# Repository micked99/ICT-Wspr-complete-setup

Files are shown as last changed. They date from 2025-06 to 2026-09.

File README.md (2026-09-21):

## Consider a donation to this projects software developer at: https://yo3ict.uus.ro/index.html press the "Show Sponsors" button  <br>

### If you do find the following compilation of information of use - [Donation](https://www.paypal.com/donate/?business=FRB6FHBJRKUK8&no_recurring=0&currency_code=SEK) <br>

# ICT-v7-ATGM336
  <br> <br>
## Updates

Fixed a bug in telemetry/gps data and moved all configurable settings into the .ino file, like channel and tcxo freq

A 180° tx with a 4x power output avalible here: https://github.com/micked99/ICT-wspr-180-4x-the-power-output

BOM and Pick and place files added if you want to for example JLCPCB to make and assamble the complete board  

BOM_ict_v361-xs.csv & CPL_pick place_ict_v361-xs.xlsx  

Screenshots of the settings of order of pcb assembly, see folder "JLCPcb order"  

Get your board online onto Sondehub/aprs.fi section added  

## Introduction
This FW is mostly the work of Eduard YO3ICT,  you can read about here: https://yo3ict.uus.ro/tracker.html  
What I have done is to simplify it even more with a few less components and a slightly easier to solder pcb.

What Eduard did was reverse enginer the [QRP-Labs](https://shop.qrp-labs.com) telemetry protocol which use wspr to get data through, and open sourced it, details of the protocol is described here: https://qrp-labs.com/flights/s4#protocol 
most balloons use this encoding today, with a few exceptions, like [Zachtek](https://www.zachtek.com)  

Another good site for beginers is to read up and join the io board at: https://groups.io/g/picoballoon 

The [Traquito](https://traquito.github.io/)  page will host channel reservation and upload to varous tracking sites like https://aprs.fi/ and https://amateur.sondehub.org/ and as well host its own map, more maps and info avalible here https://lu7aa.org/dx.asp and here http://qrp-labs.com/tracking.html, another good page that poped up lately is [wsprtv](https://wsprtv.com/docs/user_guide.html#u4b-channel-map) & [wsprtv channel map](https://wsprtv.com/tools/channel_map.html?band=17m&num_days=30&rx_threshold=1)

## Folders in this repo:  
### ICT_WSPR   
The code to upload to the board  
### Libraries
Copy the content in this folder into libraries folder of Arduino C:\Program Files (x86)\Arduino\libraries  
### Pcb-ICT-main  
Cam files for pcb ordering as well as the Eagle schematic and board files, viewer for both files here: https://www.altium365.com/viewer/
### Boards.txt-main  
Replace the Boards.txt in arduino to controll the speed of the 328, its located in: C:\Program Files (x86)\Arduino\hardware\arduino\avr  
### oscillator-main  
Test file to test the 328 and si5351, no gps is needed for this, only the 328, 5351, its tcxo and the two pull up resistors have to be soldered, if all works it will tx a carrier at 14.097Mhz, upload the .ino file with arduino or the .hex with Avrdudess https://github.com/ZakKemble/AVRDUDESS

## Goals  
This setup is aimed at three main things: light weight, low power demands and as few components as possible - easy to build

The board can be built to weigh below 1 gram fully assembled (pic below) with solar cells & antenna connected total weight 4-5 gram




To make the board consume as little power as possible its setup to switch between tx and gps so only one of the two is ON at any time, so it will startup and get valid gps lock with tx side of the board switched off, the tx ic - si5351 consumes 17-27mA (depending on model) in stb curent even when not in use so only the gps is on and draws about 25mA using the ATGM336 (N31), when the board have got a valid lock the gps will turn off and the wspr tx starts, using the low power 76, see further down, it will consume about 20mA in low and at max power, 79, it will be about 30mA, on top of this the 328 running at 2Mhz and the Tcxo combined will take another 3mA 

The board will work on any band between 80m and 2m but most used band is 20m-10m

# Features  
CW init - At power on, when sun hits the solar panels it start to tx cw, then you know you are good for launch  
Randomization - Randomize the tx by ca 5 hz each tx, have been turned off by deafult, enable in Timing.h  
No tx over selected grids - Move tx to ism (13.555) freq over selected grids  
Powerswitching between gps and tx - Will put less stress on the cells and get earlier in the morning startups  
Course altitude in main wspr - Will insert a rough altitude into the standard wspr db field, see TelemFunctions.h  
Slowly increased power in 4 steps - Default setting is 79 - Max power  
Good WDT function of 328 - Will never fail to wake up even with unstable solar cells powering the board  
Will work at low clocks, tested down to 1Mhz on the 328 - Deafult is 2Mhz  
Powersave of gps by set it to single navigational system  - See Gps section  

# GPS:

The ATGM336-N31 support both GPS and Beidou system, by switching off Beidou and run the ATGM in GPS only mode we save about 4mA, see .ino file for the command, gps only is activated by default.  
This gps does not have any altitude limit like many other modules, its been tested to 150.000m with a hack-rf and GPSSim and still worked fine

# BOM

All components but the si5351 is bought on Aliexpress, you can source the SI535/MS5351 on Ali but they can have an higher power consumption then the original, from my experience the Ali ones draw 27mA instead of 17mA in stb current  
----------------  
Cpu ATmega328

Gps ATGM336 (N31) others will work  

TX Si5351  

Tcxo 25/26/27 Mhz size 3225 3.2x2.5mm  

Xo 4Mhz size 4520 4.5mm×2mm   

2x 10K resistor size 0603, value non critical, 1K-10K works  

2x 100nF Capacitor size 0603, value non critical 10-470nF works, it will work fine without any soldered on but I recommend at least one  

2.54mm x2 Pin Header - Remove before flight by cutting it of with a scissor  

# Antennas

For gps antenna use a 46mm wire which represents a 1/4 antenna at 1575Mhz  

For tx antenna I use 0,15mm which is a good combination of strength and weigh but any wire in the 0,1 - 0,2mm will work fine.  

I use a small hook 2cm long made of 0,6mm wire bottom, and 0,8mm at the top to solder on the antenna wire, solder and twist a couple of turns arround the hook  
  <br>  
Here is good picture where you can see the Red and Yellow gps antennas  
  <br>  

Tx Antenna length calculated as normal, 300/freq x 0.95 /4

Upper antenna leg should be supported by some sort of fishing line taped to the balloon

# Solar cells

6 psc of solar cells connected in series will work fine, or 4 psc of a bit larger cells and a voltage doubler with 3,3V ldo like REG710 will do the work, ready made pcb are avalible on Aliexpress, search for "Low Noise Regulated Charge Pump" see below pic  
  <br> 

Do not try use converters with an inductor, they will not work, only converters using a capacitor are likeley to succeed.  

As can be seeen in the below picture the solar cells is intended to be soldered to the board with a center copper rod of 0,8mm, notice,  
there are two pairs of vias, one is GND and one pair is not connected to anything which is where you solder the center support for the cells - see below pic  
  <br>  
OBS! The programming pinhead should be cutoff before flight and preferably before you solder the cells onto the pcb  

solderpoints <br> 
Solderpoints for the solar cells  

With 6 x 38x19 cells ounded flat you can see a startup of the board at about 13° solar angle 

How I solder the cells together, I use a 0,6mm wire I extract from a multi stranded electrical cable, and then a very thin wire from an even smaller multi stranded cable to solder the cells to the pcb, pics:

  <br>  
  <br>  

To test the solar + board indoor before a flight you can use a Halogen flood light like below pic, I use a 400W, 8545 lumen lamp.  
-OBS- Led lamps wont work.

  <br>  

# Arduino

To compile and upload the sketch I use Arduino version 1.8.13 which you find here, others will work but not tested, https://www.arduino.cc/en/software/OldSoftwareReleases/

# 328 Fuses

Sets the expected external or internal xo used and also set the brownout to 1,8V

The 328 have an internal xo at 8Mhz, you can set it to be divided down by 8 (fuse) and then the board runs at 1Mhz
the internal xo at 8Mhz is not very stable in cold and it will not work at flying altitude, but I have tried a few flights on the internal xo divided down to 1Mhz 
and it have worked fine, anyway, both speeeds works fine for testing a board on the bench, but I do recomend that you use the suggested 4Mhz xo as in the schematic.

FD D9 FE 1,8V / External 2/4/8Mhz xo  - This is the fuses you should use if you build this board  

62 D9 FE 1.8V / internal 8Mhz osc /div8 = 1Mhz  
E2 D9 FE 1.8V / internal 8Mhz osc  

To set fuses use Avrdudess https://github.com/ZakKemble/AVRDUDESS

Fusecalc page https://www.engbedded.com/fusecalc/

I would recommend to buy a couple of arduino nano boards to practice on before flashing fuses onto a built board, as this is the main culprit of non responsive 328 - wrongly set or corrupted fuses

# Programming

The pcb is fited with a 6 pin ISP connector  
The Arduino uploads the fw with an USBasp programmer, get a 3,3v version with a 10 to 6 pin header adapter on the end of the ribbon cable  
To upload a .hex file like the one supplied in oscillator-main folder I recommend using AVRDUDESS - A GUI for AVRDUDE

https://blog.zakkemble.net/avrdudess-a-gui-for-avrdude/  
https://github.com/avrdudes/avrdude/  

Use libsusbK in Zadig to install driver for the Usbasp: https://zadig.akeo.ie/

  <br>  

In Arduino IDE select Usbasp as programmer:    
  <br>

In Boards select rAVA 2Mhz:    
  <br>  
# PCB  

  <br>  

I have always used Jlcpcb at https://jlcpcb.com/ for my balloon boards and other projects

The pcb files have been made with Eagle pcb nowadays under the name Autodesk Eagle https://www.autodesk.com/products/eagle/overview

Make the PCB as thin as possible to save weight, 0,6mm is good compromise between weight and price

In Pcb-ICT-main folder in this repo you will find needed CAM files in the zip´s, if you are a experieced with solder small parts and have a hot air solder station go with the Xtra Smal QFN version (ict_v361-xs.zip) of the board, for a more simple soldering setup use the TQFP version (ict_v361.zip)

TQFP 


Here is what a JLC-PCB assambled board looks like, pictures from Michael KC3GMG  
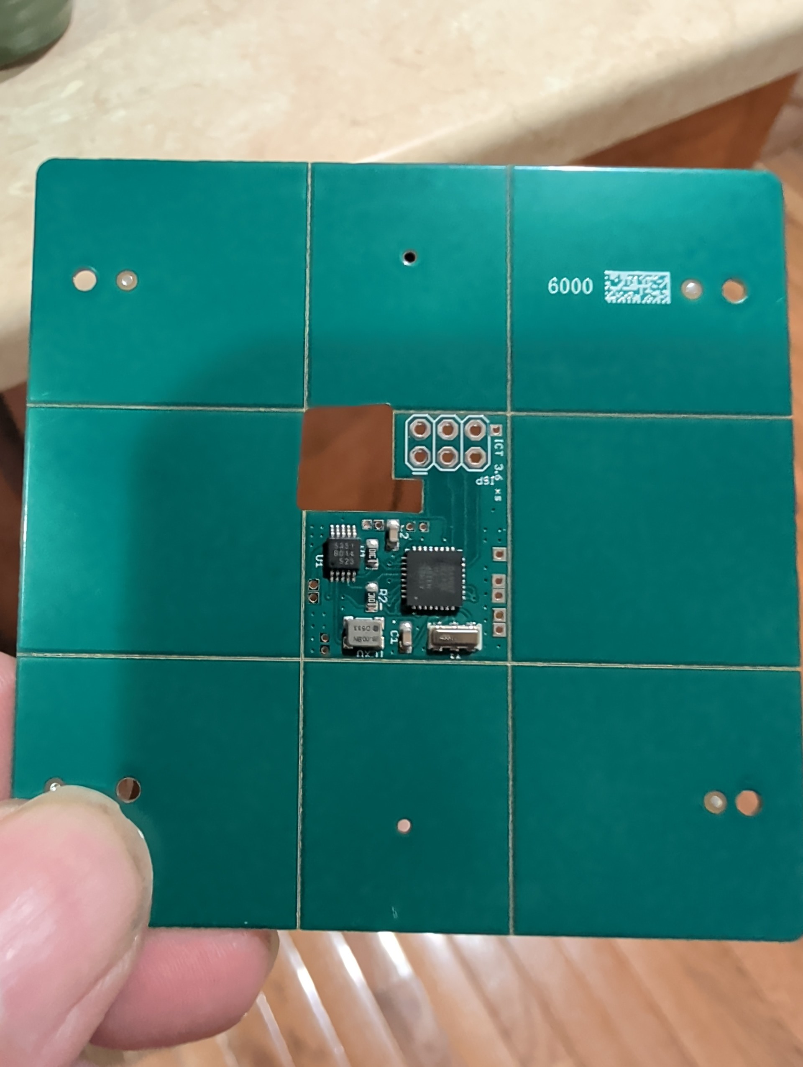
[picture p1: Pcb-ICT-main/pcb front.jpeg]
  
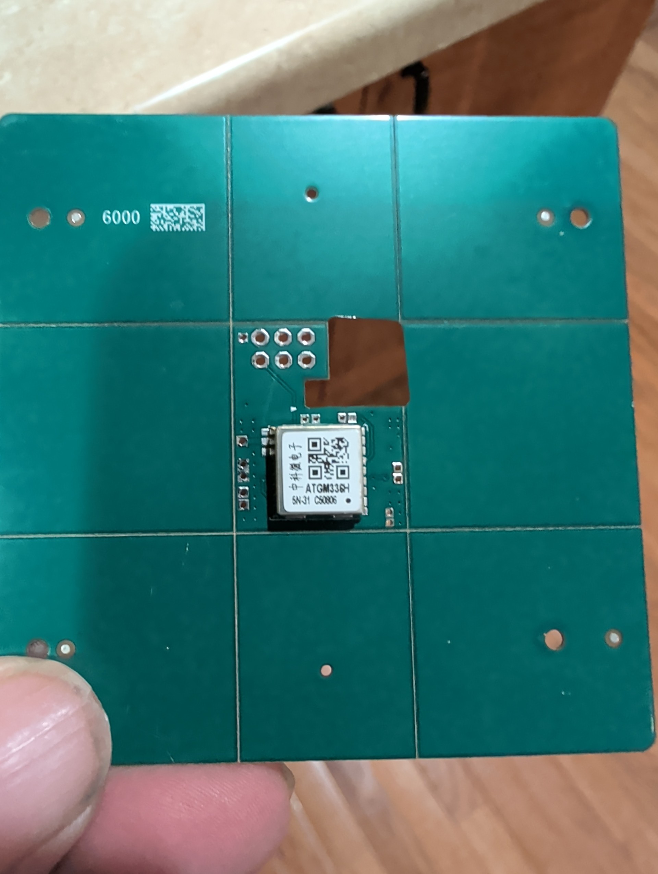
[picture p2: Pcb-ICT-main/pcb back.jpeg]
  

# Schematic  



# Setup parameters in the code  
The Arduino code is setup from start to use a 26Mhz Tcxo and to use a 4Mhz xo divided by 2 to run at 2Mhz, if other values used the code needs to be changed - see below  

Values to edit in the ino file  <br>
Follow the <<<<< arrows where you need to edit <br>

Sets the frequency and band  <br>
#define WSPR_FREQ     14097190UL // <<<<< SET TX FREQUENCY HERE <<<<<<<<<<<<<<<<<<<<<<<<<<<<<<br>

Sets your call and channel<br>
const char call[] = "SA7BSS";   // <<<<< SET WSPR CALLSIGN <<<<<<<<<<<<<<<<<<br>
char tlm_channel1 = 'Q';        // <<<<< SET TELEMETRY CHANNEL 0/1/Q <<<<<<<<br>
char tlm_channel2 = '9';        // <<<<< SET TELEMETRY CHANNEL 0-9 <<<<<<<<<<br>
 
See this page for channel setup and reservation: https://traquito.github.io/channelmap/

Set initial power of the 5351  
int pwr_level=79;  
it will for every sequence increase the power one step so if you set it at 77 it will take two sequencies, 20 min before it will start at full power   
avalible valus are 76, 77, 78 and 79 where 79 is max power, 76 is just a few mW so I recommend not to use that, the default setting is max power 79

CW setup, the board will at first moment at power on send a morse signal with your callsign<br>
Here is my SA6BSS call in the ino file  <br>
cw_s(); cw_a(); cw_6(); cw_b(); cw_s(); cw_s();  <br>

Sets the frequncy of tcxo used for the si5351 <br>
tcxo  = 26000000UL;   // <<<<< SET TCXO FREQUENCY HERE <<<<<<<<br>

Testing and Scheduling of tx sequence<br>

#include "Timing-test.h"  // <<<<< Set Timing-test.h for testing, it will tx on first 2 min slot after power on <<<<<<<<<<  <br>
#include "Timing.h"       // <<<<< Set Timing.h for flight and it will tx on the nominal 10 min scheduling <<<<<<<<<<<<<<<  <br>

Timing-test.h is a testfile that will start tx every 2min, this it convinient to use during testing on the bench, final prep before flight is to edit the  
.ino file from #include "Timing-test.h" to #include "Timing.h" this is the main config that should be used during a flight, it have a 10 min sequence as needed to fit the scheduling agreed on in the balloon community
Edit Timing.h sceduling at what minute you want to tx your normal wspr and at what minute to tx the telemetry, this can be done inside Arduino ide or with a normal texteditor  

To adjust the sequence in what order the standard and telemtry is transmitted edit Timing.h, it is set to transmitt 4 times - 8 minutes and then switching off the radio and enable gps, gets new loction data last 2 min of the 10 minute slot, then start over, default setting is: WSPR, WSPR_telemtry, WSPR, WSPR, this is set by adjusting the setModeWSPR();  or  setModeWSPR_telem(); in Timing.h file  

This is the standard setup using a 4 Mhz xo, so if you build the board with the recommended components and downloaded fw this does not need to change
Sets speed of the board  
clock_prescale_set(clock_div_2);  or clock_prescale_set(clock_div_4);  
this in conjuction with:    
#define WSPR_CTC 1334  
and select rAVA 2Mhz from boards in Arduino boards 

Alternative clocksettings:  
WSPR CTC - 2668 @ 4Mhz //1334 @ 2Mhz //667 @ 1Mhz  
And to select the appropriate board setting under Boards in Arduino,  
lets say we want to set the board to 1Mhz using a 4Mhz xo we need to set the prescaler to  
clock_prescale_set(clock_div_4);   
and set  
WSPR CTC 667  
and then select gAVA 1Mhz under boards, see section Programming  

then, for example if you wan to run it a 4Mhz set:
WSPR CTC - 2668  
mark out both of the //clock_prescale_set  
and use hAVA 4Mhz board setting  

to set cw tx frequncy adjust it in Beep.h, this will tx a short cw init as soon as you connect power<br>
     freq = 14096980UL;  <br>
  // freq = 18105900UL;  <br>
  // freq = 28125870UL;  <br>

If you have problem getting wspr decodes, say its works fine on 20m but when you try 10m the board tx but you dont get any decodes,
change this in TelemFunctions.h <br>

 //outdivider 77000000000 or 30000000000 // If bad decodes at 24/28Mhz try the other value<br> 
  outdivider = 30000000000 / frequency;  // With 900 MHz beeing the maximum internal PLL-Frequency<br> 

# Balance the board

You want the board to be as leveled as possible so the solarcells always points up and not to the sides,  
to do this use the top hook, puti it on a short loop of fishing line and bend the copper rod untill it levels up, see below:  

  <br> 

# Get your flight uploaded to Sondehub and/or aprs.fi

There is a couple of ways to get your board onto [Sondehub](https://amateur.sondehub.org/) 

The way Im doing it is to use a wspr-to-sondehub python script described here: https://github.com/micked99/wspr-to-sondehub-script
What I do is to use this script with a filtering function so your upload data dont get mixed with other flights - you should check the channel is free here before relesing a balloon:  [WSPR-TV](https://wsprtv.com/tools/channel_map.html?band=17m&num_days=30&rx_threshold=1) but as the 600 channels per band is relaying on filtering on frequency and this script cant handle that, this is a simple workarround.
So the idea I got and that DG4NOB implemented in the python upload code was that we can use the voltage reading of the battery as a filtering function, as we use solar cells, voltage is mostly of no interest, reading the Encoding [Description](https://qrp-labs.com/flights/s4#protocol) we see "Battery voltage is coded by a number in the range 0..39, which represents battery voltage in the range 3.00 to 4.95V with a resolution of 0.05V" this means we have 40 unique "channels" within this, so what we can do is to set a static value in the ict fw and uplod this to the board, <br> 
look at lines 126 - 132 in TelemFunctions.h and you see this:<br> 

  sensorVolt = sensorVolt / 5;   // mark out for fixed voltage<br> 
  volt = sensorVolt * 1.1f;      // mark out for fixed voltage<br> 
  volt = volt / 1023.0f;         // mark out for fixed voltage<br> 
  volt = volt * 4.18f;           // mark out for fixed voltage<br> 
  // volt = 3.94;                // --Remove if sensor voltage is used--<br>
  if (volt < 3.0) volt = 3.0;    // mark out for fixed voltage<br>
  if (volt > 4.95) volt = 4.95;  // mark out for fixed voltage<br>   

The normal setup is as above where the adc reads the voltage on sensorpin, it should be a voltage divider there but I have routed the pin directly to vcc so if you dont make any edits to the code it will constantly read 4.56V, so what we can do is to change the code, say we want to filter the voltage to 3,94V we edit the code to:  

 // sensorVolt = sensorVolt / 5;   // mark out for fixed voltage<br>
 // volt = sensorVolt * 1.1f;      // mark out for fixed voltage<br>
 // volt = volt / 1023.0f;         // mark out for fixed voltage<br>
 // volt = volt * 4.18f;           // mark out for fixed voltage<br>
    volt = 3.94;                   // --Remove if sensor voltage is used--<br>
 // if (volt < 3.0) volt = 3.0;    // mark out for fixed voltage<br>
 // if (volt > 4.95) volt = 4.95;  // mark out for fixed voltage<br>

After we done this and upload the code to the pcb we should have a fixed voltage reading constantly sending 3,94V which we can put in the balloon.ini file in the  [wspr upload script](https://github.com/micked99/wspr-to-sondehub-script)  

If you have launched the board with no editing to the ict code you can set 4,56V as a filter, this making it work on boards allready in flight.  

You need to double check the voltage readign your board actually tx as there will be a 0,01V variation on the actual value that comes out of the decoder, even if you set 3,94V it might be 3,95 that comes out, you can test it in this xls  
https://qrp-labs.com/images/ultimate3builder/ve3kcl/s4/308d.xls  
originating from https://qrp-labs.com/flights/s4#protocol  

Other ways to get you board online is to use https://lu7aa.org.ar/wsprset.asp  

There is also an uploader by Bill WB8ELK - maker of [Skytracker](https://elktronics.com) that you can download from [Here](https://groups.io/g/picoballoon/message/23150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)  
You need to be a member of this io board to access it, it will upload to aprs.fi and Sondehub will then automaticly pipe it onto its site,  
pros of this program is easy to setup and it can filter on Frequency as the 600 channel mapping require.  

# Misc pictures

  <br> 
  <br>

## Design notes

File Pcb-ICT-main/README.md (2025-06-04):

# ICT-PCB

Eagle PCB for my modified version of the ICT wspr setup 

This pcb is made and setup for my current version of the the ict code

ict_v361-xs // Extra small, using the QFN/MLF version of the 328 - Verified working

ict_v361 // Normal size, using the TQFP version of the 328 - untested but should work

Use .zip files for pcb ordering

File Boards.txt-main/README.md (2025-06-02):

# Boards.txt
Drop this file in Arduino IDE, it will ad the possibility to run the board at any speed of the following: 1, 2, 4, 8 & 16Mhz 

Set the prescaler, in this setup the used XO is dived with 4, so if you run a 8Mhz xo the board will run at 2Mhz            
  //clock_prescale_set(clock_div_2);             
  clock_prescale_set(clock_div_4);               
  //clock_prescale_set(clock_div_8);                    
  
edit this line: #define WSPR_CTC  1334   // CTC value for WSPR - 10672 @ 16Mhz //5336 @ 8Mhz //2668 @ 4Mhz //1334 @ 2Mhz //667 @ 1Mhz
and last choose the correct Speed under: Tools - Boards in IDE which should in this example be 2Mhz

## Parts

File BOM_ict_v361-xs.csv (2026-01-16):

Designator | Footprint | Quantity | Value | LCSC Part #
C1, C2 | 603 | 2 | C100nF_0603 | C14663
R1, R2 | 603 | 2 | R10k_0603 | C98220
GPS | SMD,9.7x10.1mm | 1 | ATGM336h-N31 | C90770
U1 | MSOP-10 | 1 | SI5351A-B-GTR | C504891
U2 | VQFN-32(5x5) | 1 | ATMEGA328P-MU | C7499261
TCXO | SMD3225-4P | 1 | KDS 1XTW26000MAA | C213404
Y1 | SMD4520-3P | 1 | CSTCR4M00G53-R0 | C22122

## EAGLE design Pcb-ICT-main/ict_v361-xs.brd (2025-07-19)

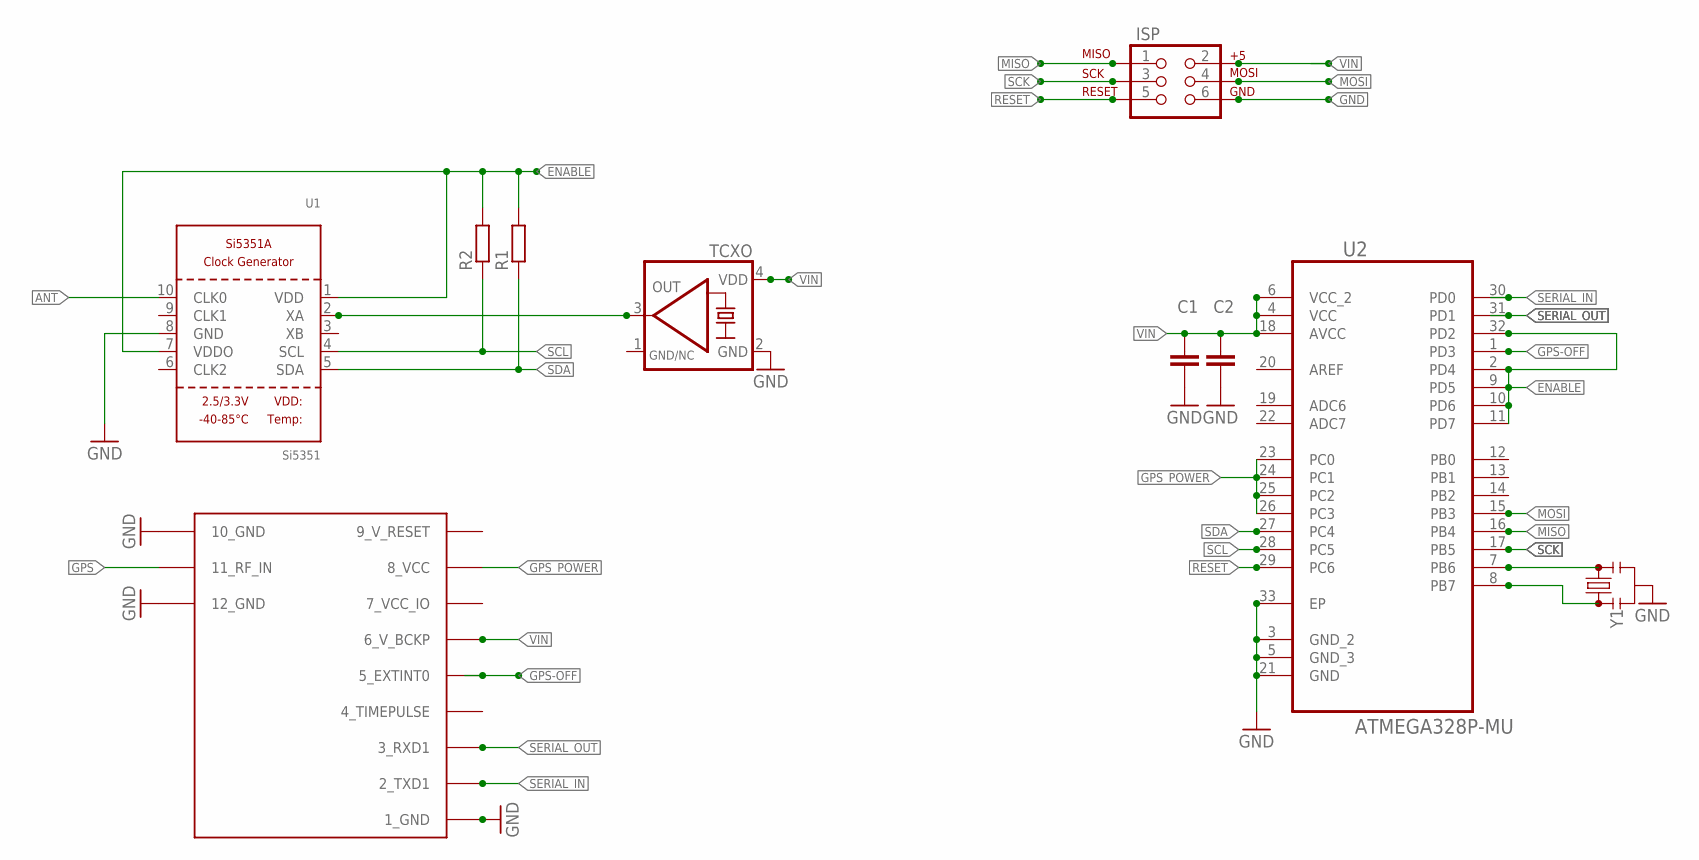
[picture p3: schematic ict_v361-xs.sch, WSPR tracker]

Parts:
C1, C2: C-EUC0603K; C0603K
GPS: UBLOX_MAX
ISP: AVR_SPI_PRG_6PTH; 2X3
R1, R2: R-EU_R0603; R0603
TCXO: KXO-TCXO-CMOS-84; 3.2X2.5_KXO-84-TCXO
U1: Si5351; MSOP10
U2: ATMEGA328P-MU; QFN50P500X500X100-33N
Y1: RESONATORSMD-4.5X2.0; RESONATOR-SMD-4.5X2.0

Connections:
7_VCC_IO: GPS.7_VCC_IO
9_V_RESET: GPS.9_V_RESET
ANT: U1.10 (CLK0)
ENABLE: R1.2, R2.2, U1.1 (VDD), U1.7 (VDDO), U2.2 (PD4), U2.9 (PD5), U2.10 (PD6), U2.11 (PD7), U2.32 (PD2)
GND: C1.2, C2.2, GPS.1_GND, GPS.10_GND, GPS.12_GND, ISP.6, TCXO.2 (GND), U1.8 (GND), U2.3 (GND_2), U2.5 (GND_3), U2.21 (GND), U2.33 (EP), Y1.2
GND/NC: TCXO.1 (GND/NC)
GPS: GPS.11_RF_IN
GPS-OFF: GPS.5_EXTINT0, U2.1 (PD3)
GPS_POWER: GPS.8_VCC, U2.23 (PC0), U2.24 (PC1), U2.25 (PC2), U2.26 (PC3)
MISO: ISP.1, U2.16 (PB4)
MOSI: ISP.4, U2.15 (PB3)
unnamed: U2.7 (PB6), Y1.3
unnamed: U2.8 (PB7), Y1.1
unnamed: TCXO.3 (OUT), U1.2 (XA)
RESET: ISP.5, U2.29 (PC6)
SCK: ISP.3, U2.17 (PB5)
SCL: R2.1, U1.4 (SCL), U2.28 (PC5)
SDA: R1.1, U1.5 (SDA), U2.27 (PC4)
SERIAL_IN: GPS.2_TXD1, U2.30 (PD0)
SERIAL_OUT: GPS.3_RXD1, U2.31 (PD1)
VIN: C1.1, C2.1, GPS.6_V_BCKP, ISP.2, TCXO.4 (VDD), U2.4 (VCC), U2.6 (VCC_2), U2.18 (AVCC)

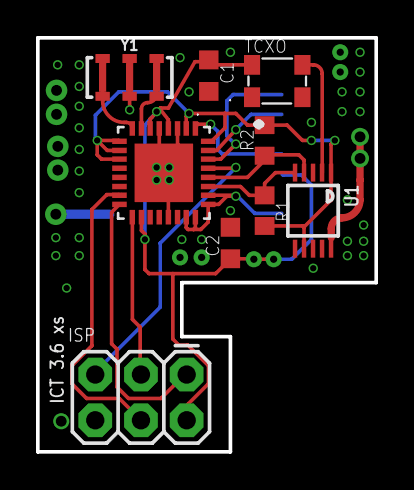
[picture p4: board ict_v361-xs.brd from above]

Board: 2 copper layers, 18.8 x 23.0 mm, 10 parts (1 on the bottom side), 16 nets.

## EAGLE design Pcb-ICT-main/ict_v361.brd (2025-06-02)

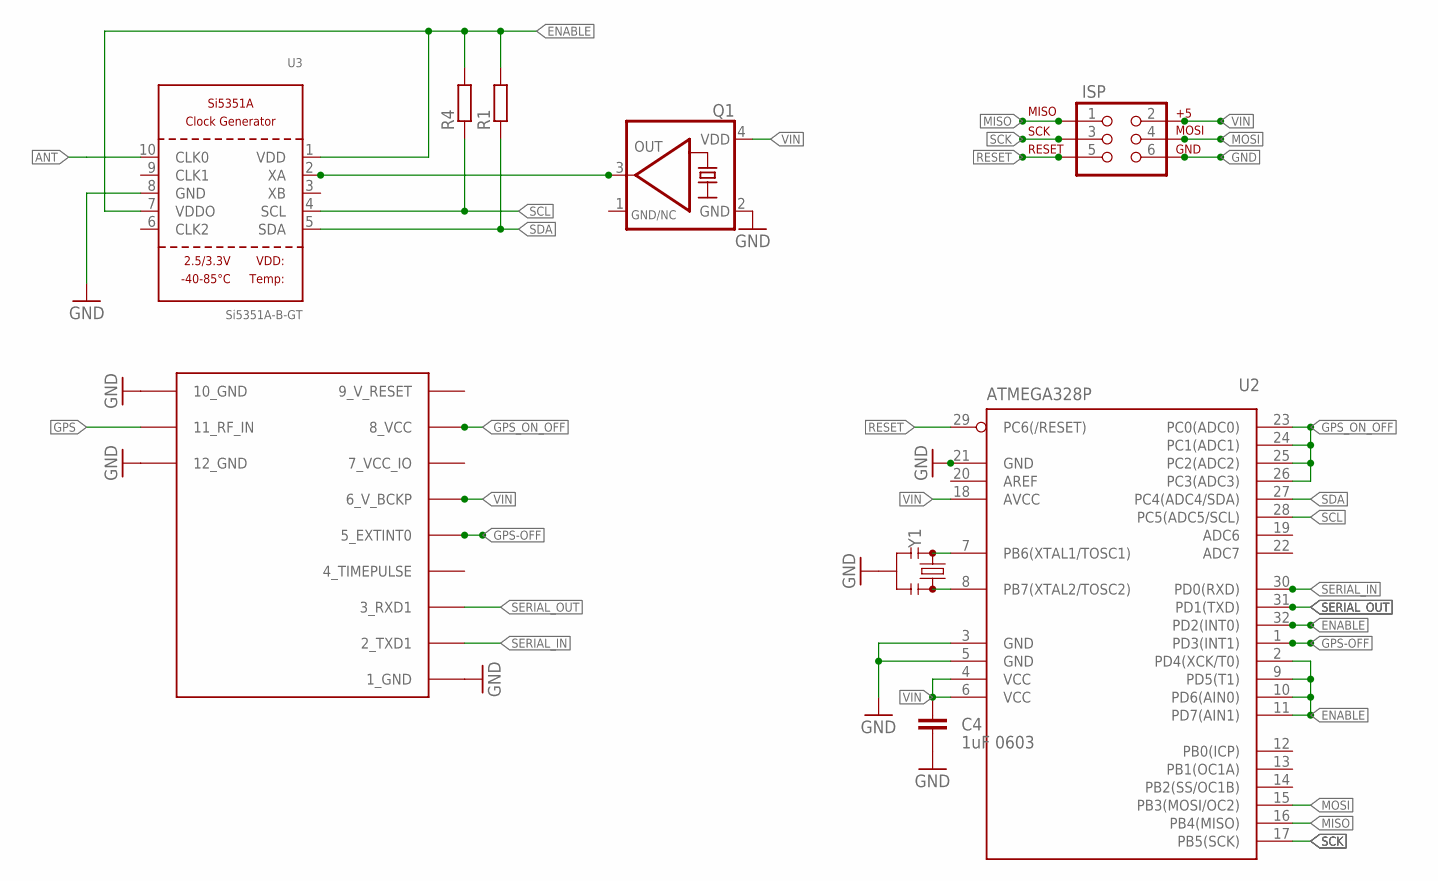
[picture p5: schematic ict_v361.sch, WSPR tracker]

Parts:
C4: 1uF 0603; C0603K
ISP: AVR_SPI_PRG_6PTH; 2X3
Q1: KXO-TCXO-CMOS-84; 3.2X2.5_KXO-84-TCXO
R1, R4: R-EU_R0603; R0603
U2: ATMEGA328P; TQFP32-08
U3: Si5351A-B-GT; MSOP10
U$2: UBLOX_MAX
Y1: RESONATORSMD-4.5X2.0; RESONATOR-SMD-4.5X2.0

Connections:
7_VCC_IO: U$2.7_VCC_IO
9_V_RESET: U$2.9_V_RESET
ANT: U3.10 (CLK0)
ENABLE: R1.2, R4.2, U2.2 (PD4(XCK/T0)), U2.9 (PD5(T1)), U2.10 (PD6(AIN0)), U2.11 (PD7(AIN1)), U2.32 (PD2(INT0)), U3.1 (VDD), U3.7 (VDDO)
GND: C4.2, ISP.6, Q1.2 (GND), U2.3 (GND), U2.5 (GND), U2.21 (GND), U3.8 (GND), U$2.1_GND, U$2.10_GND, U$2.12_GND, Y1.2
GND/NC: Q1.1 (GND/NC)
GPS: U$2.11_RF_IN
GPS-OFF: U2.1 (PD3(INT1)), U$2.5_EXTINT0
GPS_ON_OFF: U2.23 (PC0(ADC0)), U2.24 (PC1(ADC1)), U2.25 (PC2(ADC2)), U2.26 (PC3(ADC3)), U$2.8_VCC
MISO: ISP.1, U2.16 (PB4(MISO))
MOSI: ISP.4, U2.15 (PB3(MOSI/OC2))
unnamed: U2.8 (PB7(XTAL2/TOSC2)), Y1.3
unnamed: U2.7 (PB6(XTAL1/TOSC1)), Y1.1
unnamed: Q1.3 (OUT), U3.2 (XA)
RESET: ISP.5, U2.29 (PC6(/RESET))
SCK: ISP.3, U2.17 (PB5(SCK))
SCL: R4.1, U2.28 (PC5(ADC5/SCL)), U3.4 (SCL)
SDA: R1.1, U2.27 (PC4(ADC4/SDA)), U3.5 (SDA)
SERIAL_IN: U2.30 (PD0(RXD)), U$2.2_TXD1
SERIAL_OUT: U2.31 (PD1(TXD)), U$2.3_RXD1
VIN: C4.1, ISP.2, Q1.4 (VDD), U2.4 (VCC), U2.6 (VCC), U2.18 (AVCC), U$2.6_V_BCKP

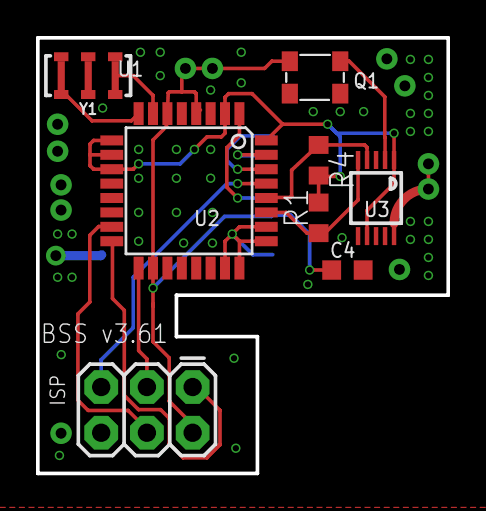
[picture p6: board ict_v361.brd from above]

Board: 2 copper layers, 22.8 x 24.2 mm, 9 parts (1 on the bottom side), 16 nets.

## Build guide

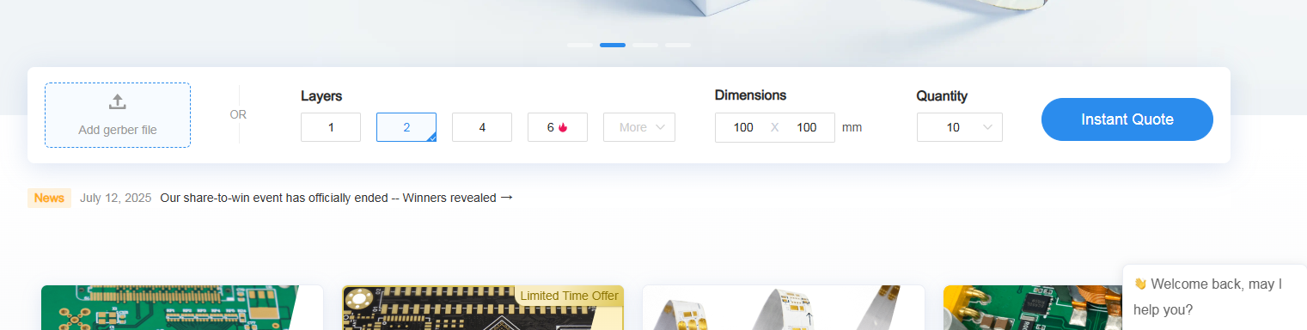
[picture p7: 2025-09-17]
JLCPcb order/2025-07-20 09_04_47-PCB Prototype & PCB Fabrication Manufacturer - JLCPCB.png

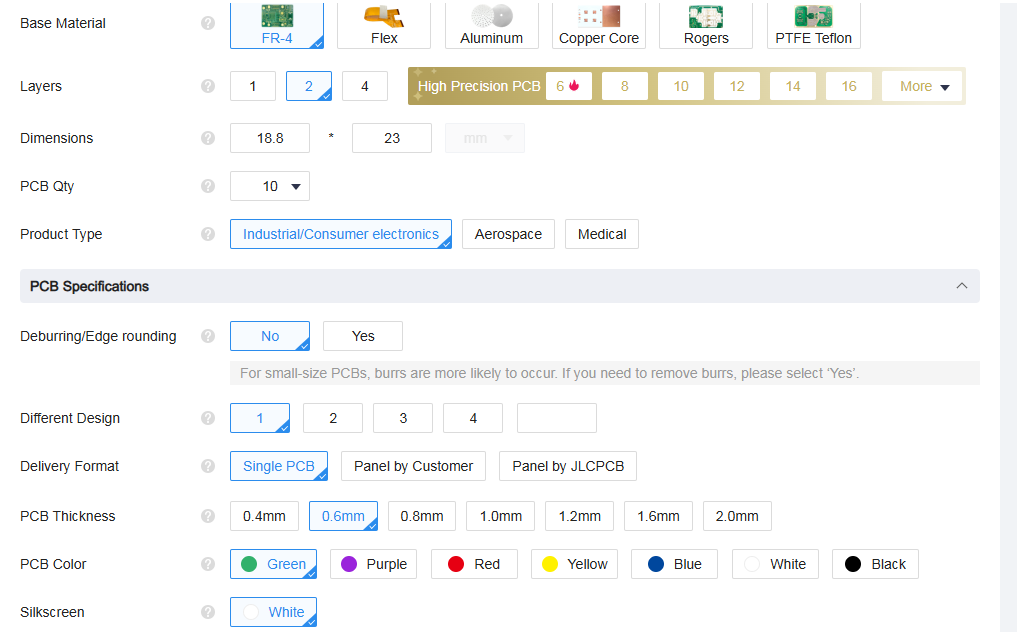
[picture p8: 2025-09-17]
JLCPcb order/2025-07-20 09_05_32-PCB Prototype & PCB Fabrication Manufacturer - JLCPCB.png

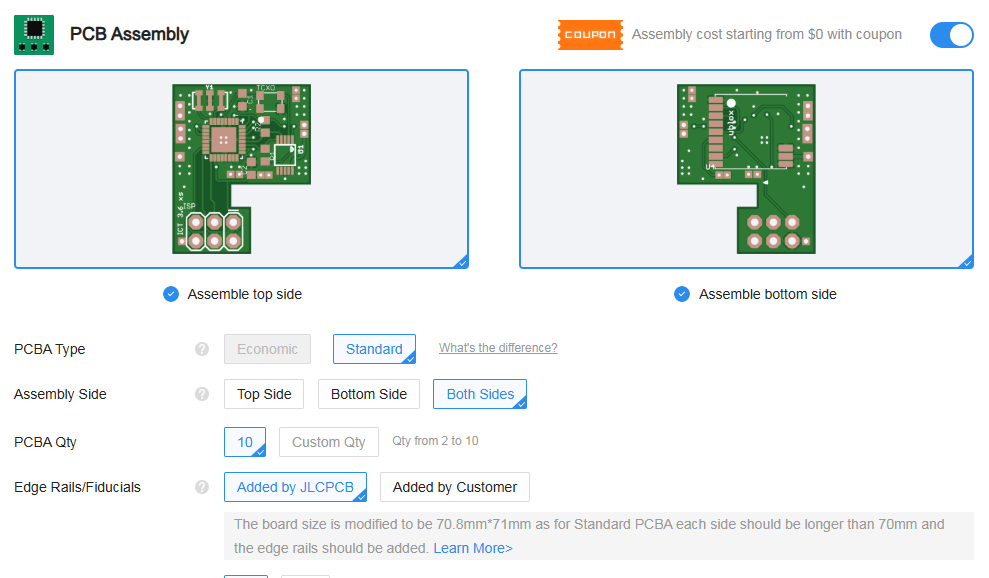
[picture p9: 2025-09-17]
JLCPcb order/2025-07-20 09_06_27-PCB Prototype & PCB Fabrication Manufacturer - JLCPCB.png

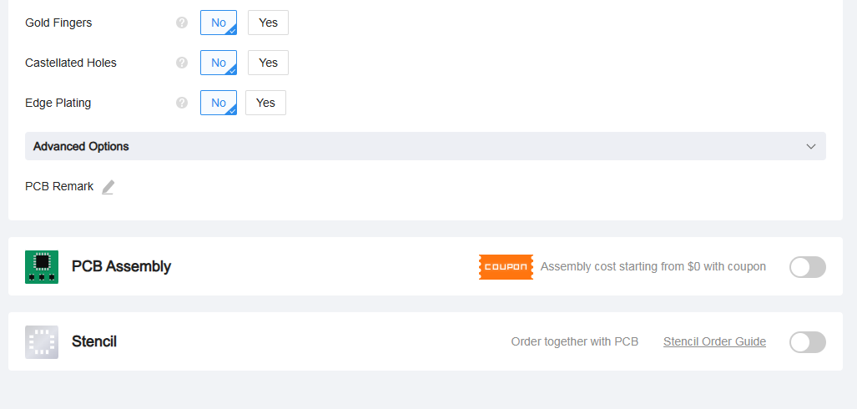
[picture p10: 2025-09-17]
JLCPcb order/2025-07-20 09_05_48-PCB Prototype & PCB Fabrication Manufacturer - JLCPCB.png

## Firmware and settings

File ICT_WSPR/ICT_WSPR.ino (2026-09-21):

//#pragma GCC diagnostic error "-Wconversion"

/*
   HABalloon by KD2NDR
   Improvements by YO3ICT
   Improvements By SA6BSS
   You may use and modify the following code to suit your needs so long as it remains open source and it is for non-commercial use only.
*/

#include <avr/wdt.h>
#include <TimeLib.h>
#include <TinyGPS++.h>
#include <JTEncode.h>
#include <Wire.h>
#include <avr/pgmspace.h>
#include <avr/power.h>

//#define WSPR_FREQ     3570185UL  // <<<<< SET TX FREQUENCY HERE <<<<<<<<<<<<<<<<<<<<<<<<<<<<<
//#define WSPR_FREQ     7040185UL  // <<<<< SET TX FREQUENCY HERE <<<<<<<<<<<<<<<<<<<<<<<<<<<<<
//#define WSPR_FREQ     10140285UL // <<<<< SET TX FREQUENCY HERE <<<<<<<<<<<<<<<<<<<<<<<<<<<<<
#define WSPR_FREQ     14097190UL   // <<<<< SET TX FREQUENCY HERE <<<<<<<<<<<<<<<<<<<<<<<<<<<<<
// #define WSPR_FREQ    18106230UL // <<<<< SET TX FREQUENCY HERE <<<<<<<<<<<<<<<<<<<<<<<<<<<<<
//#define WSPR_FREQ     21096150UL // <<<<< SET TX FREQUENCY HERE <<<<<<<<<<<<<<<<<<<<<<<<<<<<<        
//#define WSPR_FREQ     28126235UL // <<<<< SET TX FREQUENCY HERE <<<<<<<<<<<<<<<<<<<<<<<<<<<<<
#define ISM_WSPR_FREQ   13555425UL // = 1,500Hz audio on 13.553.900 Mhz // 13555425UL New correct ism freq
#define WSPR_CTC        1334       // WSPR CTC - 2668 @ 4Mhz //1334 @ 2Mhz //667 @ 1Mhz


// Enumerations
enum mode {MODE_WSPR};
TinyGPSPlus gps;
JTEncode jtencode;

// Global variables
unsigned long freq;
const char call[] = "SA7BSS";   // <<<<< SET WSPR CALLSIGN <<<<<<<<<<<<<<<<<<<<<<<<<<<<<<<<<<<<<<<
char tlm_channel1 = 'Q';        // <<<<< SET TELEMETRY CHANNEL 0/1/Q <<<<<<<<<<<<<<<<<<<<<<<<<<<<<
char tlm_channel2 = '9';        // <<<<< SET TELEMETRY CHANNEL 0-9 <<<<<<<<<<<<<<<<<<<<<<<<<<<<<<<
uint32_t tcxo;                  // TCXO/crystal frequency in Hz, set in setup()
uint32_t pll_c;                 // "c" part of feedback multiplier XTAL->PLL, set in setup()
char call_telemetry[7];         // WSPR telemetry callsign
char loc_telemetry[5];          // WSPR telemetry locator
char TestGrid[5];               // Testing grid for Geofence
uint8_t dbm, dbm_telemetry;     // Standard WSPR dbm - coarse altitude & WSPR telemetry dbm
//char message_jt9[14] = "";    // JT9 Message (13 char limit)
char loc4[5];                   // 4 digit gridsquare locator
byte Hour, Minute, Second;      // Used for timing
long lat, lon, oldlat, oldlon;  // Used for location
uint8_t tx_buffer[255];         // WSPR Tx buffer
uint8_t symbol_count;           // JTencode
uint16_t tone_delay, tone_spacing, CTC; // JTencode
int alt_meters = 0;
int telemetry_set = 0;
int Sats = 0;
int gps_speed = 0;
volatile bool proceed = false;
long lastMillis = 0; 
int pwr_level=79;               // Set between 76-79, to slowly increase power to ease load on the solar cells at low solar angles, 76 is really low so use from 77 and up.
int w=1;
bool Outside = true;            // Geofence flag
//GeoFence grids by Matt Downs - 2E1GYP //Airborne transmissions of this sort are not legal over North Korea and Yemen
const char NoTXGrids[] PROGMEM = {"PN31 PN41 PN20 PN30 PN40 PM29 PM39 PM28 PM38 LK16 LK15 LK14 LK13 LK23 LK24 LK25 LK26 LK36 LK35 LK34 LK33 LK44 LK45 LK46 LK47 LK48 LK58 LK57 LK56 LK55"};

#include "TelemFunctions.h"     // Various telemetry functions
#include "Beep.h"               // Beeps and CW at power on
//#include "Timing-test.h"      // <<<<< Set Timing-test.h for testing, it will tx on first 2 min slot after power on <<<<<<<<<<
#include "Timing.h"             // <<<<< Set Timing.h for flight and it will tx on the nominal 10 min scheduling <<<<<<<<<<<<<<<

// Function Prototype
void wdt_init(void) __attribute__ ((naked, used, section(".init3")));
// Function Implementation
void wdt_init(void)
 {
  MCUSR = 0x00;  //Clear all reset flags
  WDTCSR |= (1 << WDCE) | (1 << WDE);
  WDTCSR = (1 << WDP3) | (1 << WDP0);
  return;
 }

void setup()
 {
  cli(); //Disable global interrupts
  WDTCSR |= (1 << WDCE) | (1 << WDE);
  WDTCSR = (0 << WDIE) | (1 << WDE) | (1 << WDP3) | (1 << WDP0);  // First enable the watchdog timer
  sei(); //Enable global interrupts

  tcxo  = 26000000UL;   // <<<<< SET TCXO FREQUENCY HERE <<<<<<<<<<<<<<<<<<<<<<<<<<<<<
  pll_c = 924000UL;     // "c" part of PLL feedback multiplier

  clock_prescale_set(clock_div_2);
  //clock_prescale_set(clock_div_4);

  pinMode(2, OUTPUT);  // Si5351 off
  pinMode(4, OUTPUT);
  pinMode(5, OUTPUT);
  pinMode(6, OUTPUT);
  pinMode(7, OUTPUT);
  
  cw_s(); cw_a(); cw_6(); cw_b(); cw_s(); cw_s(); // Set callsign of the CW id at startup
  
  delay(80);
  pinMode(A0, OUTPUT); // GPS VCC on
  pinMode(A1, OUTPUT);
  pinMode(A2, OUTPUT);
  pinMode(A3, OUTPUT);
  digitalWrite(A0, HIGH);
  digitalWrite(A1, HIGH);
  digitalWrite(A2, HIGH);
  digitalWrite(A3, HIGH);
  delay(1500);
  Serial.begin(9600);

  //delay(2500); Serial.write("$PMTK886,3*2B\r\n");   //set balloon mode for QUECTEL L70 GPS module
  delay(2500); Serial.write("$PCAS04,1*18\r\n");      //GPS only ATGM336
  //delay(2500); Serial.write("$PCAS04,2*1B\r\n");    //BD  only ATGM336
  //delay(2500); Serial.write("$PCAS04,7*1E\r\n");    //All ATGM336 
  //delay(2500); Serial.print("$PSIMNAV,W,3*3A\r\n"); //Sets Balloon mode of L70
  //delay(2500); Serial.write("$PMTK127*36\r\n");     //Erase EPO data stored in the flash memory - L70
  //delay(2500); Serial.write("$PMTK120*31\r\n");     //Erase aiding data stored in the flash memory - L70
  //delay(2500); Serial.write("$PMTK104*37\r\n");     //resets the GNSS module to the factory default - L70

  wdt_reset();
 }

ISR(TIMER1_COMPA_vect) // Interrupt to drive the TX timing
 {  proceed = true; }

void loop()
 {
  wdt_reset();
  while (Serial.available() > 0)
  if (gps.encode(Serial.read()))            // GPS related functions need to be in here to work with tinyGPS Plus library
  {
    wdt_reset();
  }
  if (gps.location.isValid())
  {
  if (timeStatus() == timeNotSet)           // Only sets time if already not done previously
  {
    setGPStime();                           // Sets system time to GPS UTC time for sync
  }
    TXtiming();                             // Process timing
  }
  }

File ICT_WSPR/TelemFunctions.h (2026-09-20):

/*
   Telemetry functions
*/

void setGPStime() // Sets the system time from the GPS
 {
  if (gps.time.isValid())
 {
    Hour = gps.time.hour();
    Minute = gps.time.minute();
    Second = gps.time.second();
    setTime(Hour, Minute, Second, 1, 1, 2000); // (hr,min,sec,day,month,yr)
 }
 }

void locjt9() // Calculates full locator from GPS
 {
  lon = (gps.location.lng() * 100000) + 18000000L;
  lat = (gps.location.lat() * 100000) +  9000000L;
  char MH[13] = {'A', 'A', 'A', 'A', 'A', 'A', '-', 'A', 'A', 'A', 'A', 'A', 'A'};
  MH[5] += lat % 25;
  unsigned long q = lat / 25;
  MH[4] += q % 25;
  q = q / 25;
  MH[3] += q % 25;
  q = q / 25;
  MH[2] += q % 25;
  q = q / 25;
  MH[1] += q % 25;
  MH[0] += q / 25;
  MH[12] += lon % 25;
  q = lon / 25;
  MH[11] += q % 25;
  q = q / 25;
  MH[10] += q % 25;
  q = q / 25;
  MH[9] += q % 25;
  q = q / 25;
  MH[8] += q % 25;
  MH[7] += q / 25;
  String locjt9_txt = "";
  int i = 0;
  while (i < 13) {
  locjt9_txt += MH[i];
  i++;
 }
 // locjt9_txt.toCharArray(message_jt9, 14);
 }

void loc4calc() // Determine the locator from the GPS data
 {
  lon = (gps.location.lng() * 100000) + 18000000L;
  lat = (gps.location.lat() * 100000) +  9000000L;
  char MH[4] = {'A', 'A', '0', '0'};
  MH[0] +=  lon / 2000000;
  MH[1] +=  lat / 1000000;
  MH[2] += (lon % 2000000) / 200000;
  MH[3] += (lat % 1000000) / 100000;
  String loc4_txt = "";
  int i = 0;
  while (i < 4) {
    loc4_txt += MH[i];
    i++;
 }
  loc4_txt.toCharArray(loc4, 5);
 }

void call_telem() // Determine the telemetry callsign
 {
  alt_meters = gps.altitude.meters();
  char MH[2] = {'A', 'A'};
  MH[0] += ((lon % 200000) / 8333);
  MH[1] += ((lat % 100000) / 4166);
  call_telemetry[0] = tlm_channel1;
  call_telemetry[2] = tlm_channel2;
  int a = MH[0] - 'A';
  int b = MH[1] - 'A';
  int c = a * 24 + b;
  int d = int(alt_meters / 20);
  long e = (long)(1068L * c + d);
  long f = float(e / 17576L);
  if (f < 10)
  call_telemetry[1] = f + '0';
  else
  call_telemetry[1] = f - 10 + 'A';
  long g = e - f * 17576L;
  int h = int(g / 676);
  call_telemetry[3] = h + 'A';
  long i = g - h * 676L;
  int j = int(i / 26);
  call_telemetry[4] = j + 'A';
  long k = i - j * 26L;
  int l = int(k / 1);
  call_telemetry[5] = l + 'A';
 }

void loc_dbm_telem() // Determine the locator and dBm value for the telemetry transmission
 {
  Sats =  gps.satellites.value();
  gps_speed = gps.speed.knots();
  int wADC = 0;
  int temp = 0;
  float volt = 0;
  int sensorVolt = 0;
  ADMUX = (_BV(REFS1) | _BV(REFS0) | _BV(MUX3));
  ADCSRA |= _BV(ADEN);
  delay(20);
  for (int i=0;i<5;i++)
 {
  ADCSRA |= _BV(ADSC);
  while (bit_is_set(ADCSRA, ADSC));
  wADC = wADC + ADCW;
  delay(20);
 }
  wADC = wADC / 5;
  temp = (wADC - 305.11 ) / 1.15;
  delay(20);
  analogReference(INTERNAL);
  for (int i=0;i<5;i++)
 {
  sensorVolt = sensorVolt + analogRead(0); //analogRead(0) for the old boards
 }
  sensorVolt = sensorVolt / 5;   // mark out for fixed voltage
  volt = sensorVolt * 1.1f;      // mark out for fixed voltage
  volt = volt / 1023.0f;         // mark out for fixed voltage
  volt = volt * 4.18f;           // mark out for fixed voltage
 // volt = 3.54;                     // Remove if sensor voltage is used
  if (volt < 3.0) volt = 3.0;    // mark out for fixed voltage
  if (volt > 4.95) volt = 4.95;  // mark out for fixed voltage
  if (temp < -49) temp = -49;
  if (temp > 39) temp = 39;
  int GPS = 0;
  if ((lon != oldlon) || (lat != oldlat))
  GPS = 1;
  else
  GPS = 0;
  oldlon = lon;
  oldlat = lat;
  if (Sats < 5) Sats = 0; else Sats = 1;
  int temp_raw = (int)(1024L * (temp * 0.01 + 2.73)) / 5;
  temp_raw = (int)(temp_raw - 457) / 2;
  float batt_raw = (int)(1024L * volt) / 5;
  batt_raw = (batt_raw - 614) / 10;
  float round_number = round(batt_raw);
  if (round_number > batt_raw) round_number = round_number - 1;
  batt_raw = (int)round_number;
  long x = (temp_raw * 40L ) + batt_raw;
  long y = (x * 42L) + (int)gps_speed / 2;
  long z = (y * 2L) + (int)GPS;
  long xy = (z * 2L) + (int)Sats;
  long a = (int)(xy / 34200L);
  loc_telemetry[0] = a + 'A';
  long b = xy - (34200L * a);
  long c = (int)(b / 1900L);
  loc_telemetry[1] = c + 'A';
  long d = b - (1900L * c);
  long e = (int)(d / 190L);
  loc_telemetry[2] = e + '0';
  long f = d - (190L * e);
  long g = (int) (f / 19L);
  loc_telemetry[3] = g + '0';
  dbm_telemetry = f - (g * 19L);
  if (dbm_telemetry == 0) dbm_telemetry = 0;
  else if (dbm_telemetry == 1) dbm_telemetry = 3;
  else if (dbm_telemetry == 2) dbm_telemetry = 7;
  else if (dbm_telemetry == 3) dbm_telemetry = 10;
  else if (dbm_telemetry == 4) dbm_telemetry = 13;
  else if (dbm_telemetry == 5) dbm_telemetry = 17;
  else if (dbm_telemetry == 6) dbm_telemetry = 20;
  else if (dbm_telemetry == 7) dbm_telemetry = 23;
  else if (dbm_telemetry == 8) dbm_telemetry = 27;
  else if (dbm_telemetry == 9) dbm_telemetry = 30;
  else if (dbm_telemetry == 10) dbm_telemetry = 33;
  else if (dbm_telemetry == 11) dbm_telemetry = 37;
  else if (dbm_telemetry == 12) dbm_telemetry = 40;
  else if (dbm_telemetry == 13) dbm_telemetry = 43;
  else if (dbm_telemetry == 14) dbm_telemetry = 47;
  else if (dbm_telemetry == 15) dbm_telemetry = 50;
  else if (dbm_telemetry == 16) dbm_telemetry = 53;
  else if (dbm_telemetry == 17) dbm_telemetry = 57;
  else if (dbm_telemetry == 18) dbm_telemetry = 60;
 }
 
#define WSPR_TONE_SPACING  146     // ~1.46 Hz
#define WSPR_DELAY         683     // Delay value for WSPR

 void geofence_check()
 {
  Outside = true;
  for (unsigned int GridLoop = 0; GridLoop < sizeof(NoTXGrids); GridLoop = GridLoop + 5) //Iterate between Geo-Fenced grids
 {
  for (int CharLoop = 0; CharLoop < 4; CharLoop++)
 {
      TestGrid[CharLoop] = pgm_read_byte_near (NoTXGrids + CharLoop + GridLoop);  //Copy a Grid string from program memory to RAM variable.
 }
  if ((loc4[0] == TestGrid[0]) && (loc4[1] == TestGrid[1]) && (loc4[2] == TestGrid[2]) && (loc4[3] == TestGrid[3])) {
      Outside = false; //We found a match between the current location and a Geo-Fenced Grid
      break;
 }
 }
 }

 void dbm_alt() // Coarse altitude for WSPR standard message dBm value
 {
/*  
alt_meters = gps.altitude.meters();
if (alt_meters >= 15000) dbm = 60;
else if (alt_meters >= 14600) dbm = 57;
else if (alt_meters >= 14200) dbm = 53;
else if (alt_meters >= 13800) dbm = 50;
else if (alt_meters >= 13400) dbm = 47;
else if (alt_meters >= 13000) dbm = 43;
else if (alt_meters >= 12600) dbm = 40;
else if (alt_meters >= 12200) dbm = 37;
else if (alt_meters >= 11800) dbm = 33;
else if (alt_meters >= 11400) dbm = 30;
else if (alt_meters >= 11000) dbm = 27;
else if (alt_meters >= 10600) dbm = 23;
else if (alt_meters >= 10200) dbm = 20;
else if (alt_meters >= 9800) dbm = 17;
else if (alt_meters >= 8000) dbm = 13;
else if (alt_meters >= 6000) dbm = 10;
else if (alt_meters >= 3000) dbm = 7;
else if (alt_meters >= 1000) dbm = 3;
else dbm = 0;  
*/
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

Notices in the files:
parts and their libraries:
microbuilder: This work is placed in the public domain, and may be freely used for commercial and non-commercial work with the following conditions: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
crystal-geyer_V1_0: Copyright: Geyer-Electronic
